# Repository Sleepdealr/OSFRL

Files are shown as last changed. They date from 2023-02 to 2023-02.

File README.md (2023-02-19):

# OSFRL

FRL PCB made with STM32F072 and Molex EZMate

Source PCB files provided in the `PCB/` folder, with firmware source in the `Firmware/` folder

These have been tested and are working

<br />This work is licensed under a <a rel="license" href="http://creativecommons.org/licenses/by-nc-sa/4.0/">Creative Commons Attribution-NonCommercial-ShareAlike 4.0 Unported License</a>.

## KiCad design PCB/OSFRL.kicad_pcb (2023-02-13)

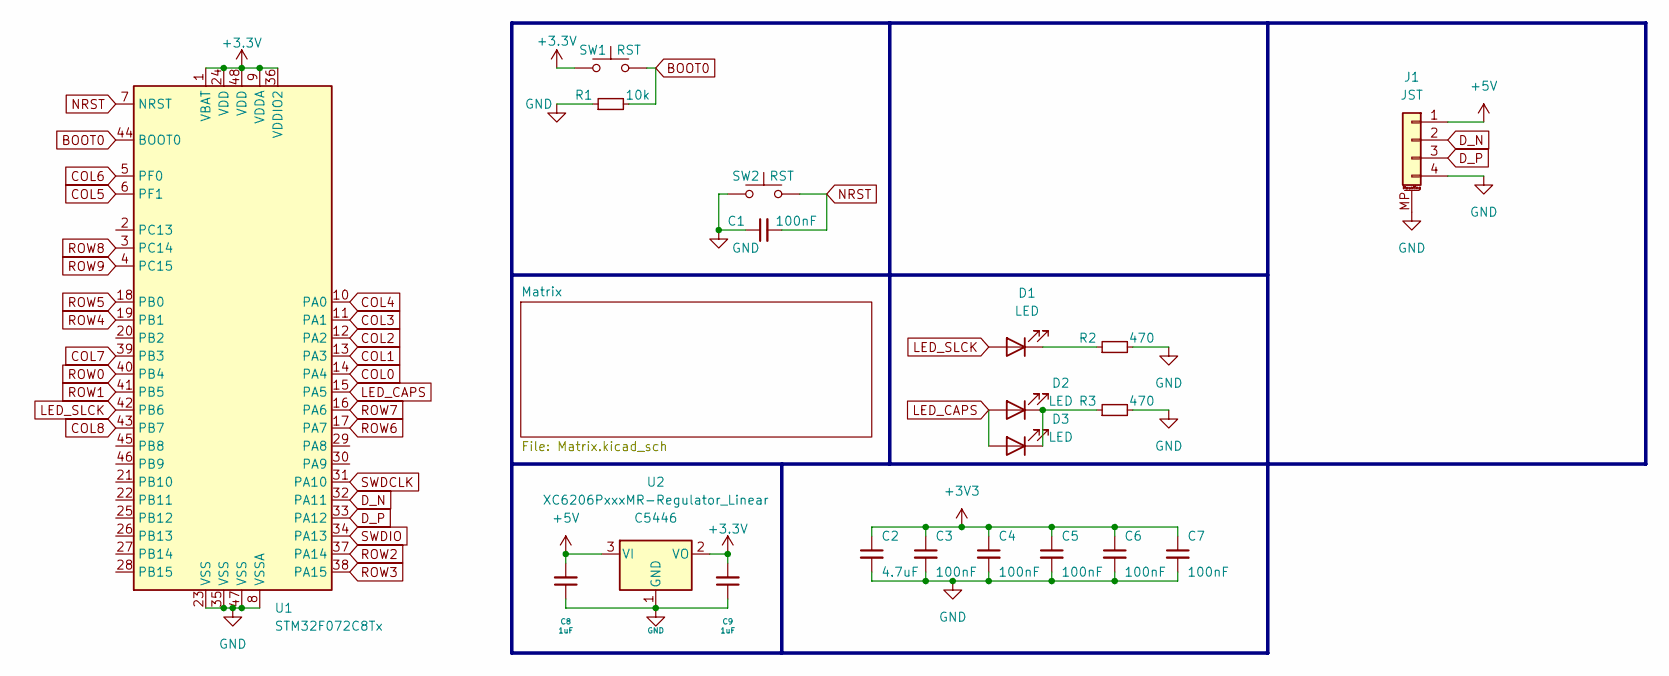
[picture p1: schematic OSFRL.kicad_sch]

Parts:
C1, C3, C4, C5, C6, C7: 100nF; C_0402_1005Metric; LCSC C307331
C2: 4.7uF; C_0402_1005Metric; LCSC C52923
C8, C9: 1uF; C_0402_1005Metric; LCSC C52923
D1, D2: LED; LED_MX_3mm
D3: LED; LED_MX_3mm-FLIPPED
J1: JST; MOLEX_781710004_MountingReliefs; LCSC C145956
R1: 10k; R_0402_1005Metric
R2, R3: 470; R_0402_1005Metric
SW1, SW2: RST; SW_SPST_SKQG_WithoutStem
U1: STM32F072C8Tx; LQFP-48_7x7mm_P0.5mm
U2: XC6206PxxxMR-Regulator_Linear; SOT-23; LCSC C5446

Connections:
+5V: C8.2, J1.1, U2.3 (VI)
BOOT0: R1.2, SW1.2, U1.44 (BOOT0)
COL0: U1.14 (PA4); also elsewhere on the board
COL1: U1.13 (PA3); also elsewhere on the board
COL2: U1.12 (PA2); also elsewhere on the board
COL3: U1.11 (PA1); also elsewhere on the board
COL4: U1.10 (PA0); also elsewhere on the board
COL5: U1.6 (PF1); also elsewhere on the board
COL6: U1.5 (PF0); also elsewhere on the board
COL7: U1.39 (PB3); also elsewhere on the board
COL8: U1.43 (PB7); also elsewhere on the board
D_N: J1.2, U1.32 (PA11)
D_P: J1.3, U1.33 (PA12)
GND: C1.1, C2.2, C3.2, C4.2, C5.2, C6.2, C7.2, C8.1, C9.1, J1.4, J1.MP (MountPin), R1.1, R2.2, R3.2, SW2.1, U1.8 (VSSA), U1.23 (VSS), U1.35 (VSS), U1.47 (VSS), U2.1 (GND)
LED_CAPS: D2.2 (A), D3.2 (A), U1.15 (PA5)
LED_SLCK: D1.2 (A), U1.42 (PB6)
NRST: C1.2, SW2.2, U1.7 (NRST)
unnamed: D1.1 (K), R2.1
unnamed: D2.1 (K), D3.1 (K), R3.1
ROW0: U1.40 (PB4); also elsewhere on the board
ROW1: U1.41 (PB5); also elsewhere on the board
ROW2: U1.37 (PA14); also elsewhere on the board
ROW3: U1.38 (PA15); also elsewhere on the board
ROW4: U1.19 (PB1); also elsewhere on the board
ROW5: U1.18 (PB0); also elsewhere on the board
ROW6: U1.17 (PA7); also elsewhere on the board
ROW7: U1.16 (PA6); also elsewhere on the board
ROW8: U1.3 (PC14); also elsewhere on the board
ROW9: U1.4 (PC15); also elsewhere on the board
SWDCLK: U1.31 (PA10)
SWDIO: U1.34 (PA13)

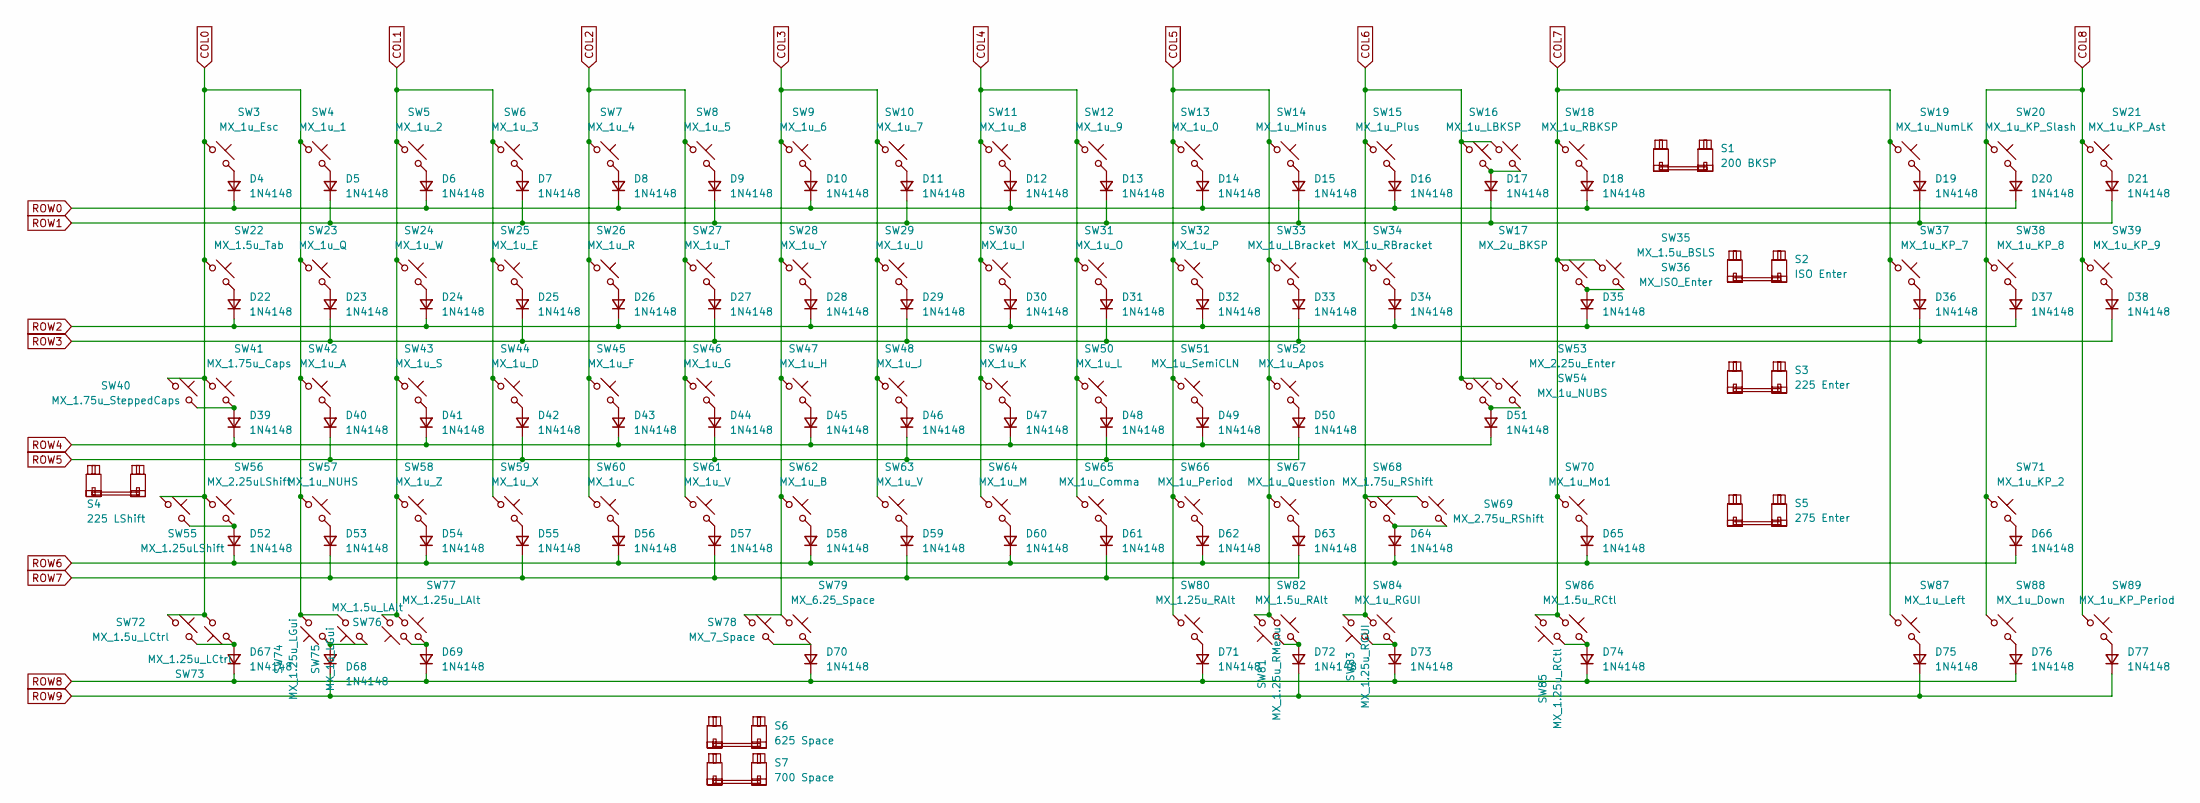
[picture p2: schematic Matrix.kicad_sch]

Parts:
D4, D5, D6, D7, D8, D9, D10, D11, D12, D13, D14, D15, D16, D17, D18, D19, D20, D21, D22, D23, D24, D25, D26, D27, D28, D29, D30, D31, D32, D33, D34, D35, D36, D37, D38, D39, D40, D41, D42, D43, D44, D45, D46, D47, D48, D49, D50, D51, D52, D53, D54, D55, D56, D57, D58, D59, D60, D61, D62, D63, D64, D65, D66, D67, D68, D69, D70, D71, D72, D73, D74, D75, D76, D77: 1N4148; D_SOD-123-EditSkilk
S1: 200 BKSP; STAB_MX_P_2u
S2: ISO Enter; STAB_MX_P_ISO_FLIPPED
S3: 225 Enter; STAB_MX_P_2.25u
S4: 225 LShift; STAB_MX_P_2.25u
S5: 275 Enter; STAB_MX_P_2.75u
S6: 625 Space; STAB_MX_P_6.25u
S7: 700 Space; STAB_MX_P_7u
SW3: MX_1u_Esc; SW_MX_1u
SW4: MX_1u_1; SW_MX_1u
SW5: MX_1u_2; SW_MX_1u
SW6: MX_1u_3; SW_MX_1u
SW7: MX_1u_4; SW_MX_1u
SW8: MX_1u_5; SW_MX_1u
SW9: MX_1u_6; SW_MX_1u
SW10: MX_1u_7; SW_MX_1u
SW11: MX_1u_8; SW_MX_1u
SW12: MX_1u_9; SW_MX_1u
SW13: MX_1u_0; SW_MX_1u
SW14: MX_1u_Minus; SW_MX_1u
SW15: MX_1u_Plus; SW_MX_1u
SW16: MX_1u_LBKSP; SW_MX_1u
SW17: MX_2u_BKSP; SW_MX_1u
SW18: MX_1u_RBKSP; SW_MX_1u
SW19: MX_1u_NumLK; SW_MX_1u
SW20: MX_1u_KP_Slash; SW_MX_1u
SW21: MX_1u_KP_Ast; SW_MX_1u
SW22: MX_1.5u_Tab; SW_MX_1.5u
SW23: MX_1u_Q; SW_MX_1u
SW24: MX_1u_W; SW_MX_1u
SW25: MX_1u_E; SW_MX_1u
SW26: MX_1u_R; SW_MX_1u
SW27: MX_1u_T; SW_MX_1u
SW28: MX_1u_Y; SW_MX_1u
SW29: MX_1u_U; SW_MX_1u
SW30: MX_1u_I; SW_MX_1u
SW31: MX_1u_O; SW_MX_1u
SW32: MX_1u_P; SW_MX_1u
SW33: MX_1u_LBracket; SW_MX_1u
SW34: MX_1u_RBracket; SW_MX_1u
SW35: MX_1.5u_BSLS; SW_MX_1.5u
SW36: MX_ISO_Enter; SW_MX_1u
SW37: MX_1u_KP_7; SW_MX_1u
SW38: MX_1u_KP_8; SW_MX_1u
SW39: MX_1u_KP_9; SW_MX_1u
SW40: MX_1.75u_SteppedCaps; SW_MX_1.75u_stp
SW41: MX_1.75u_Caps; SW_MX_1.75u
SW42: MX_1u_A; SW_MX_1u
SW43: MX_1u_S; SW_MX_1u
SW44: MX_1u_D; SW_MX_1u
SW45: MX_1u_F; SW_MX_1u
SW46: MX_1u_G; SW_MX_1u
SW47: MX_1u_H; SW_MX_1u
SW48: MX_1u_J; SW_MX_1u
SW49: MX_1u_K; SW_MX_1u
SW50: MX_1u_L; SW_MX_1u
SW51: MX_1u_SemiCLN; SW_MX_1u
SW52: MX_1u_Apos; SW_MX_1u
SW53: MX_2.25u_Enter; SW_MX_1u
SW54: MX_1u_NUBS; SW_MX_1u
SW55: MX_1.25uLShift; SW_MX_1.25u
SW56: MX_2.25uLShift; SW_MX_1u
SW57: MX_1u_NUHS; SW_MX_1u
SW58: MX_1u_Z; SW_MX_1u
SW59: MX_1u_X; SW_MX_1u
SW60: MX_1u_C; SW_MX_1u
SW61, SW63: MX_1u_V; SW_MX_1u
SW62: MX_1u_B; SW_MX_1u
SW64: MX_1u_M; SW_MX_1u
SW65: MX_1u_Comma; SW_MX_1u
SW66: MX_1u_Period; SW_MX_1u
SW67: MX_1u_Question; SW_MX_1u
SW68: MX_1.75u_RShift; SW_MX_1.75u
SW69: MX_2.75u_RShift; SW_MX_1u
SW70: MX_1u_Mo1; SW_MX_1u
SW71: MX_1u_KP_2; SW_MX_1u
SW72: MX_1.5u_LCtrl; SW_MX_1.5u
SW73: MX_1.25u_LCtrl; SW_MX_1.25u
SW74: MX_1.25u_LGui; SW_MX_1.25u
SW75: MX_1u_LGui; SW_MX_1u
SW76: MX_1.5u_LAlt; SW_MX_1.5u
SW77: MX_1.25u_LAlt; SW_MX_1.25u
SW78: MX_7_Space; SW_MX_1u
SW79: MX_6.25_Space; SW_MX_1u
SW80: MX_1.25u_RAlt; SW_MX_1.25u
SW81: MX_1.25u_RMenu; SW_MX_1.25u
SW82: MX_1.5u_RAlt; SW_MX_1.5u
SW83: MX_1.25u_RGUI; SW_MX_1.25u
SW84: MX_1u_RGUI; SW_MX_1u
SW85: MX_1.25u_RCtl; SW_MX_1.25u
SW86: MX_1.5u_RCtl; SW_MX_1.5u
SW87: MX_1u_Left; SW_MX_1u
SW88: MX_1u_Down; SW_MX_1u
SW89: MX_1u_KP_Period; SW_MX_1u

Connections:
COL0: SW3.1, SW4.1, SW22.1, SW23.1, SW40.1, SW41.1, SW42.1, SW55.1, SW56.1, SW57.1, SW72.1, SW73.1, SW74.1, SW75.1; also elsewhere on the board
COL1: SW5.1, SW6.1, SW24.1, SW25.1, SW43.1, SW44.1, SW58.1, SW59.1, SW76.1, SW77.1; also elsewhere on the board
COL2: SW7.1, SW8.1, SW26.1, SW27.1, SW45.1, SW46.1, SW60.1, SW61.1; also elsewhere on the board
COL3: SW9.1, SW10.1, SW28.1, SW29.1, SW47.1, SW48.1, SW62.1, SW63.1, SW78.1, SW79.1; also elsewhere on the board
COL4: SW11.1, SW12.1, SW30.1, SW31.1, SW49.1, SW50.1, SW64.1, SW65.1; also elsewhere on the board
COL5: SW13.1, SW14.1, SW32.1, SW33.1, SW51.1, SW52.1, SW66.1, SW67.1, SW80.1, SW81.1, SW82.1; also elsewhere on the board
COL6: SW15.1, SW16.1, SW17.1, SW34.1, SW53.1, SW54.1, SW68.1, SW69.1, SW83.1, SW84.1; also elsewhere on the board
COL7: SW18.1, SW19.1, SW35.1, SW36.1, SW37.1, SW70.1, SW85.1, SW86.1, SW87.1; also elsewhere on the board
COL8: SW20.1, SW21.1, SW38.1, SW39.1, SW71.1, SW88.1, SW89.1; also elsewhere on the board
unnamed: D4.2 (A), SW3.2
unnamed: D5.2 (A), SW4.2
unnamed: D6.2 (A), SW5.2
unnamed: D7.2 (A), SW6.2
unnamed: D8.2 (A), SW7.2
unnamed: D9.2 (A), SW8.2
unnamed: D10.2 (A), SW9.2
unnamed: D11.2 (A), SW10.2
unnamed: D12.2 (A), SW11.2
unnamed: D13.2 (A), SW12.2
unnamed: D14.2 (A), SW13.2
unnamed: D15.2 (A), SW14.2
unnamed: D16.2 (A), SW15.2
unnamed: D17.2 (A), SW16.2, SW17.2
unnamed: D18.2 (A), SW18.2
unnamed: D19.2 (A), SW19.2
unnamed: D20.2 (A), SW20.2
unnamed: D21.2 (A), SW21.2
unnamed: D22.2 (A), SW22.2
unnamed: D23.2 (A), SW23.2
unnamed: D24.2 (A), SW24.2
unnamed: D25.2 (A), SW25.2
unnamed: D26.2 (A), SW26.2
unnamed: D27.2 (A), SW27.2
unnamed: D28.2 (A), SW28.2
unnamed: D29.2 (A), SW29.2
unnamed: D30.2 (A), SW30.2
unnamed: D31.2 (A), SW31.2
unnamed: D32.2 (A), SW32.2
unnamed: D33.2 (A), SW33.2
unnamed: D34.2 (A), SW34.2
unnamed: D35.2 (A), SW35.2, SW36.2
unnamed: D36.2 (A), SW37.2
unnamed: D37.2 (A), SW38.2
unnamed: D38.2 (A), SW39.2
unnamed: D39.2 (A), SW40.2, SW41.2
unnamed: D40.2 (A), SW42.2
unnamed: D41.2 (A), SW43.2
unnamed: D42.2 (A), SW44.2
unnamed: D43.2 (A), SW45.2
unnamed: D44.2 (A), SW46.2
unnamed: D45.2 (A), SW47.2
unnamed: D46.2 (A), SW48.2
unnamed: D47.2 (A), SW49.2
unnamed: D48.2 (A), SW50.2
unnamed: D49.2 (A), SW51.2
unnamed: D50.2 (A), SW52.2
unnamed: D51.2 (A), SW53.2, SW54.2
unnamed: D52.2 (A), SW55.2, SW56.2
unnamed: D53.2 (A), SW57.2
unnamed: D54.2 (A), SW58.2
unnamed: D55.2 (A), SW59.2
unnamed: D56.2 (A), SW60.2
unnamed: D57.2 (A), SW61.2
unnamed: D58.2 (A), SW62.2
unnamed: D59.2 (A), SW63.2
unnamed: D60.2 (A), SW64.2
unnamed: D61.2 (A), SW65.2
unnamed: D62.2 (A), SW66.2
unnamed: D63.2 (A), SW67.2
unnamed: D64.2 (A), SW68.2, SW69.2
unnamed: D65.2 (A), SW70.2
unnamed: D66.2 (A), SW71.2
unnamed: D67.2 (A), SW72.2, SW73.2
unnamed: D68.2 (A), SW74.2, SW75.2
unnamed: D69.2 (A), SW76.2, SW77.2
unnamed: D70.2 (A), SW78.2, SW79.2
unnamed: D71.2 (A), SW80.2
unnamed: D72.2 (A), SW81.2, SW82.2
unnamed: D73.2 (A), SW83.2, SW84.2
unnamed: D74.2 (A), SW85.2, SW86.2
unnamed: D75.2 (A), SW87.2
unnamed: D76.2 (A), SW88.2
unnamed: D77.2 (A), SW89.2
ROW0: D4.1 (K), D6.1 (K), D8.1 (K), D10.1 (K), D12.1 (K), D14.1 (K), D16.1 (K), D18.1 (K), D20.1 (K); also elsewhere on the board
ROW1: D5.1 (K), D7.1 (K), D9.1 (K), D11.1 (K), D13.1 (K), D15.1 (K), D17.1 (K), D19.1 (K), D21.1 (K); also elsewhere on the board
ROW2: D22.1 (K), D24.1 (K), D26.1 (K), D28.1 (K), D30.1 (K), D32.1 (K), D34.1 (K), D35.1 (K), D37.1 (K); also elsewhere on the board
ROW3: D23.1 (K), D25.1 (K), D27.1 (K), D29.1 (K), D31.1 (K), D33.1 (K), D36.1 (K), D38.1 (K); also elsewhere on the board
ROW4: D39.1 (K), D41.1 (K), D43.1 (K), D45.1 (K), D47.1 (K), D49.1 (K), D51.1 (K); also elsewhere on the board
ROW5: D40.1 (K), D42.1 (K), D44.1 (K), D46.1 (K), D48.1 (K), D50.1 (K); also elsewhere on the board
ROW6: D52.1 (K), D54.1 (K), D56.1 (K), D58.1 (K), D60.1 (K), D62.1 (K), D64.1 (K), D65.1 (K), D66.1 (K); also elsewhere on the board
ROW7: D53.1 (K), D55.1 (K), D57.1 (K), D59.1 (K), D61.1 (K), D63.1 (K); also elsewhere on the board
ROW8: D67.1 (K), D69.1 (K), D70.1 (K), D71.1 (K), D73.1 (K), D74.1 (K), D76.1 (K); also elsewhere on the board
ROW9: D68.1 (K), D72.1 (K), D75.1 (K), D77.1 (K); also elsewhere on the board

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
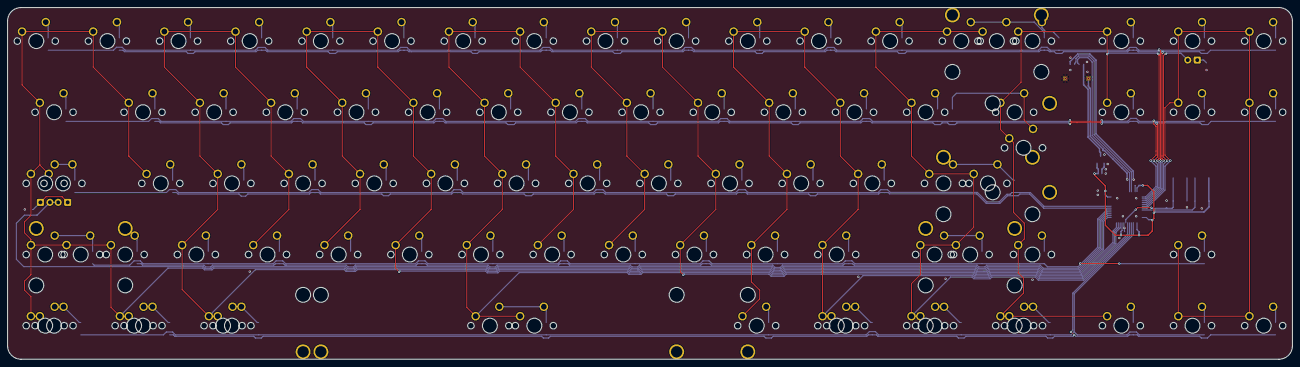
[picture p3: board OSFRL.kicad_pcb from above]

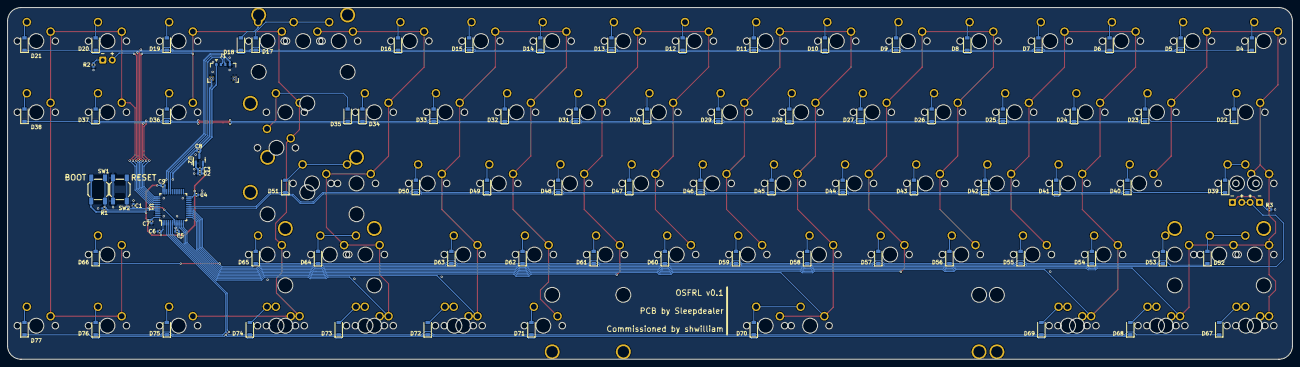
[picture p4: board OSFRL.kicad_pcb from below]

Board: 2 copper layers, 344.0 x 94.1 mm, 188 parts (91 on the bottom side), 104 nets.
